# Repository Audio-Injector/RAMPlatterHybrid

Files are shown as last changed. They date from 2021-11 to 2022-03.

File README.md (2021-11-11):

# RAM Platter Hybrid

Hybrid software / hardware DJ kit

RAM Platter Hybrid

The RAM Platter Hybrid is a hardware and software to allow digital DJing of your music.

The system implements speed change resampling in hardware. The software provides the interface and controls the audio (direction) and other signal processing.

By performing resampling in hardware, the majority of the core signal processing does not burden the CPU. This allows the system to run on low power devices. It should also allow the system latency (time lag between moving the record and hearing it move) to be reduced.

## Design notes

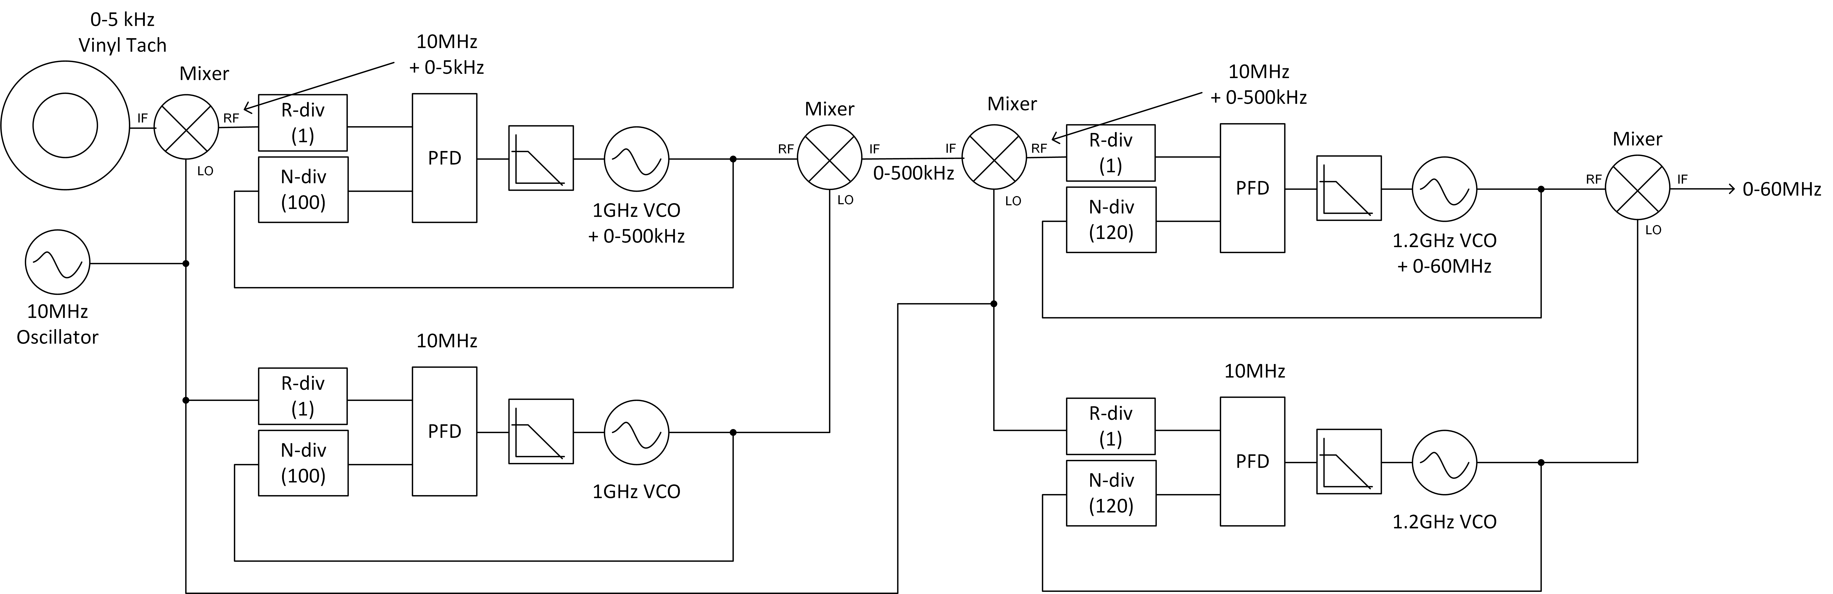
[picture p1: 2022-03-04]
electronics/wikiFigs/cascaded.mixer.png

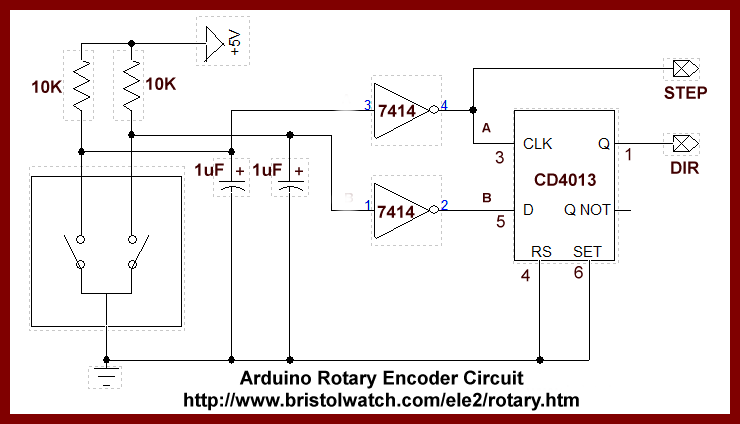
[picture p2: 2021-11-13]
electronics/datasheets/rot_enc.png

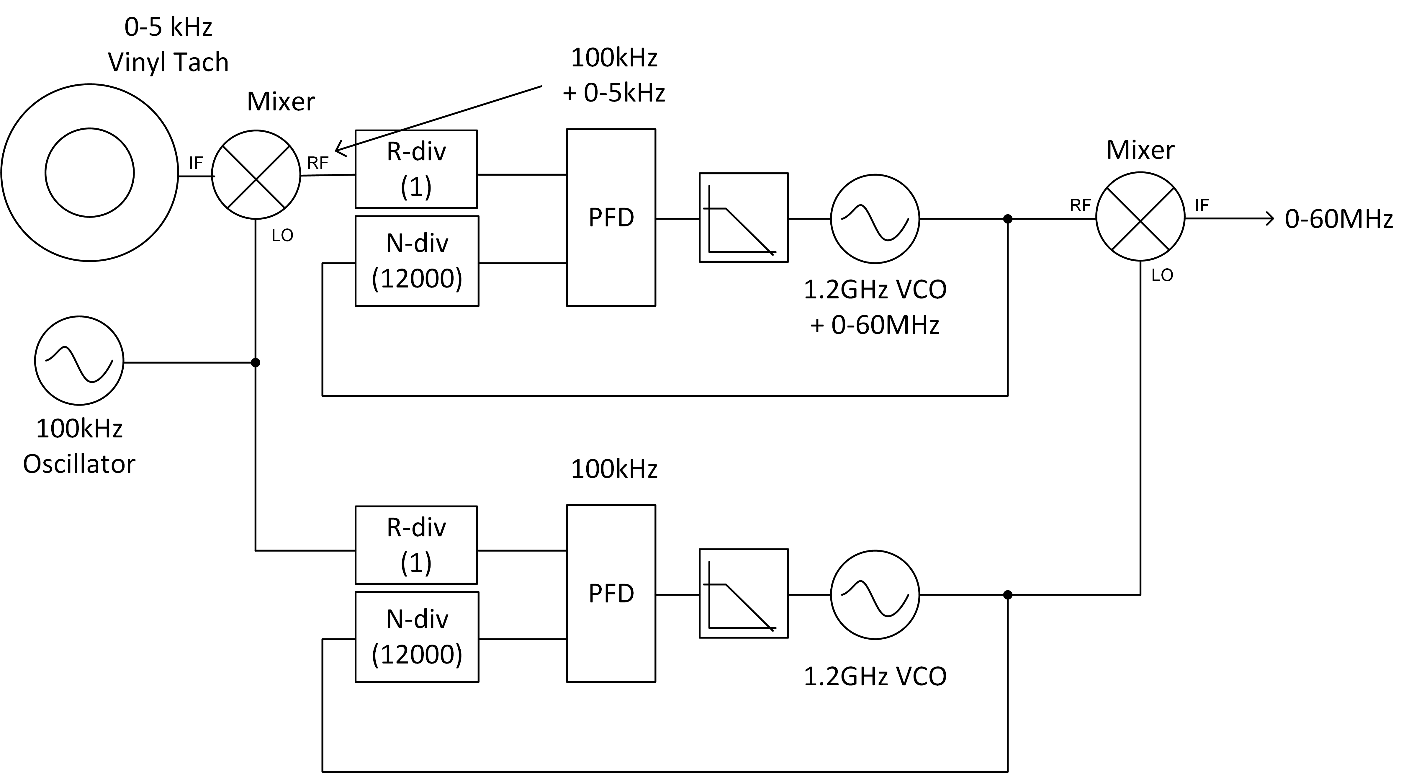
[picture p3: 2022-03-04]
electronics/wikiFigs/RFMixer.png

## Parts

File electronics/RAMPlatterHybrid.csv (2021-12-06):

Id | Designator | Package | Quantity | Designation | Supplier and ref
1 | U6 | SOIC-24W_7.5x15.4mm_P1.27mm | 1 | CD74HC4059
2 | R5,R6 | R_0603_1608Metric | 2 | 100R
3 | R7,R8,R9,R10 | R_0603_1608Metric | 4 | 75R
4 | U4,U3 | AV2-8.4-10 | 2 | AV2-8.4-10
5 | U7 | SOT-223-3_TabPin2 | 1 | AP1117-33
6 | U8 | QFN-32-1EP_5x5mm_P0.5mm_EP3.3x3.3mm | 1 | WM8750
7 | J1 | PinHeader_2x20_P2.54mm_Vertical | 1 | Raspberry_Pi_2_3
8 | C1,C2,C20 | C_0603_1608Metric | 3 | 2.5n
9 | C3,C4,C5,C6,C7,C9,C15,C17,C18,C19,C21,C22 | C_0603_1608Metric | 12 | 100n
10 | R1,R2 | R_0603_1608Metric | 2 | 20R
11 | R3,R4,R11 | R_0603_1608Metric | 3 | 10k
12 | U1 | SOP-8_3.9x4.9mm_P1.27mm | 1 | LM358
13 | U2 | TSSOP-14_4.4x5mm_P0.65mm | 1 | 74LVC74APW
14 | C23 | C_0603_1608Metric | 1 | 20n
15 | R12 | R_0603_1608Metric | 1 | 150k
16 | U5 | SOP-16_3.9x9.9mm_P1.27mm | 1 | HC4046A
17 | JP1,JP2,JP3 | SolderJumper-2_P1.3mm_Bridged_Pad1.0x1.5mm | 3 | SolderJumper_2_Bridged
18 | C8,C10,C16 | CP_Elec_4x5.3 | 3 | 10u
19 | C11,C12,C13,C14 | CP_Elec_4x5.3 | 4 | 1u NP

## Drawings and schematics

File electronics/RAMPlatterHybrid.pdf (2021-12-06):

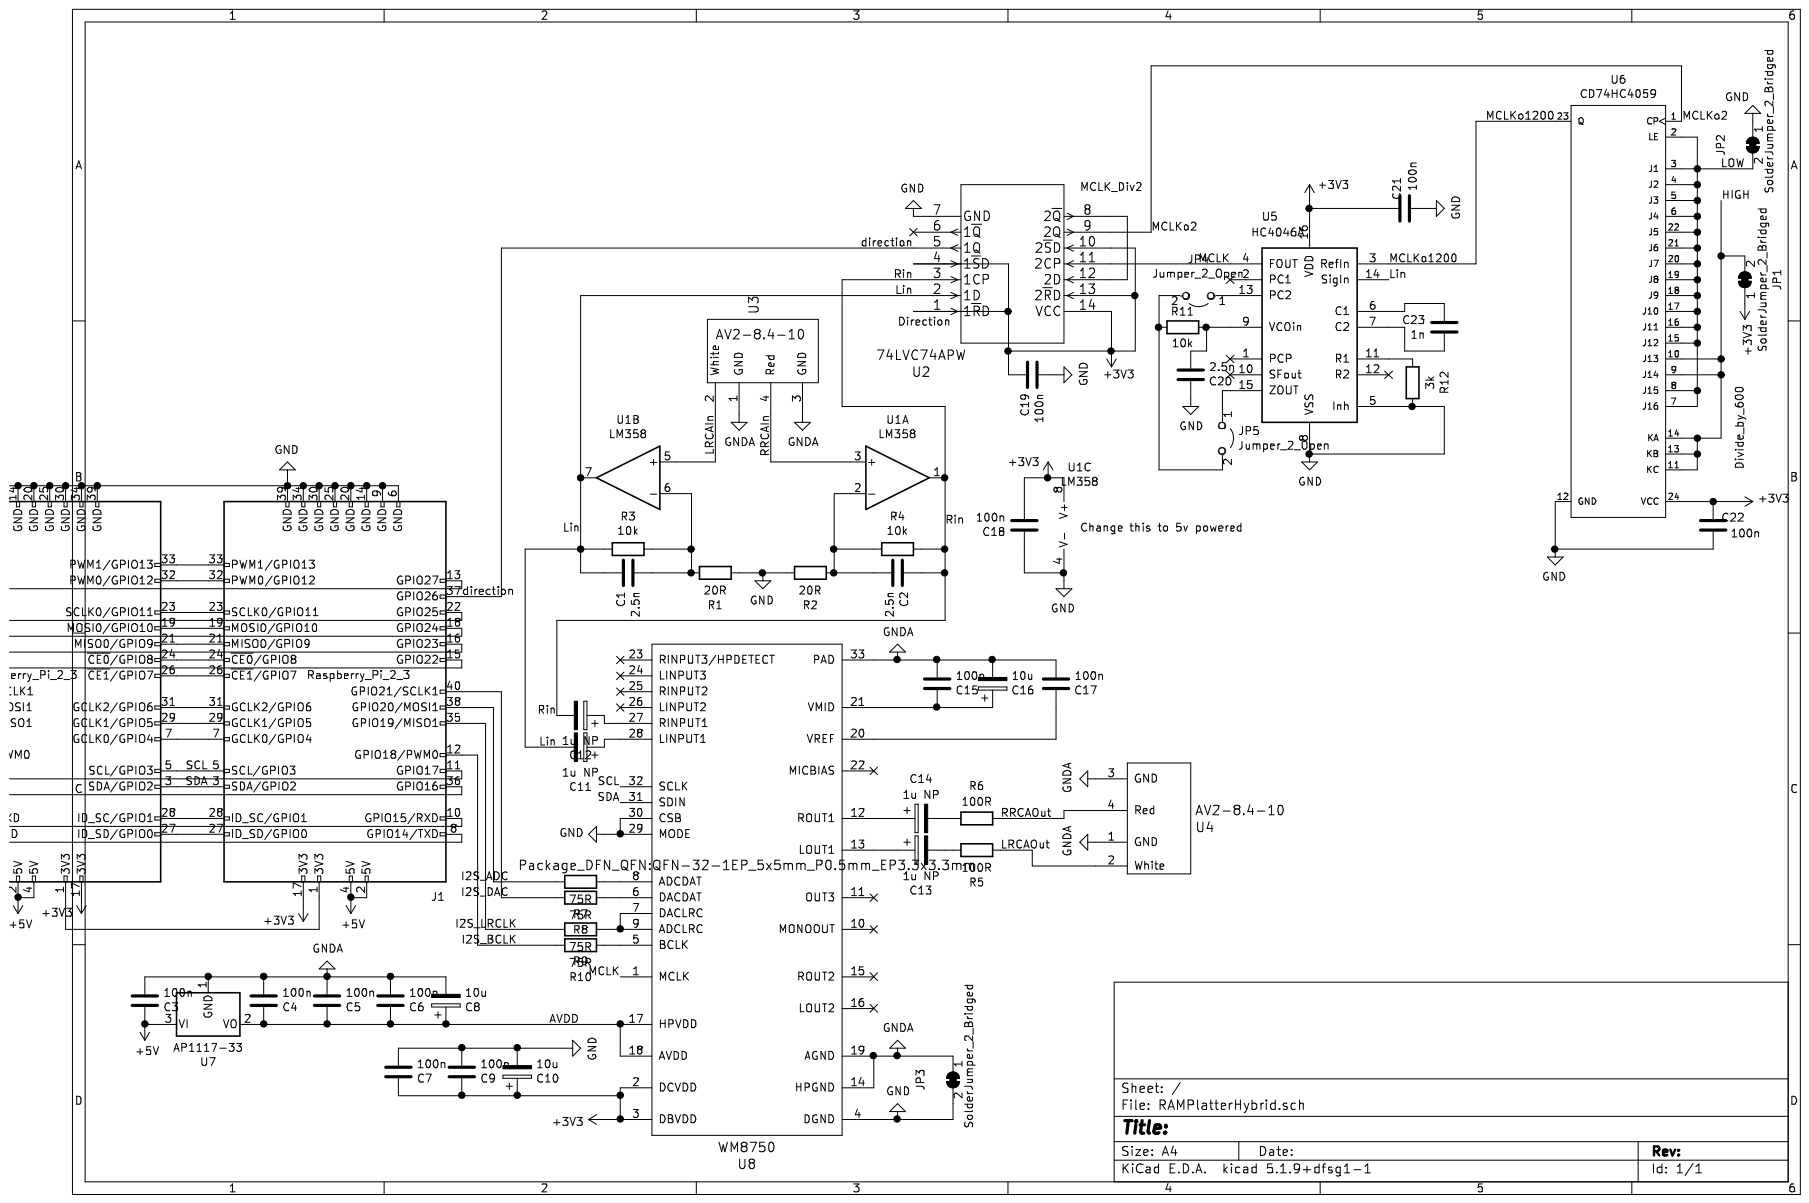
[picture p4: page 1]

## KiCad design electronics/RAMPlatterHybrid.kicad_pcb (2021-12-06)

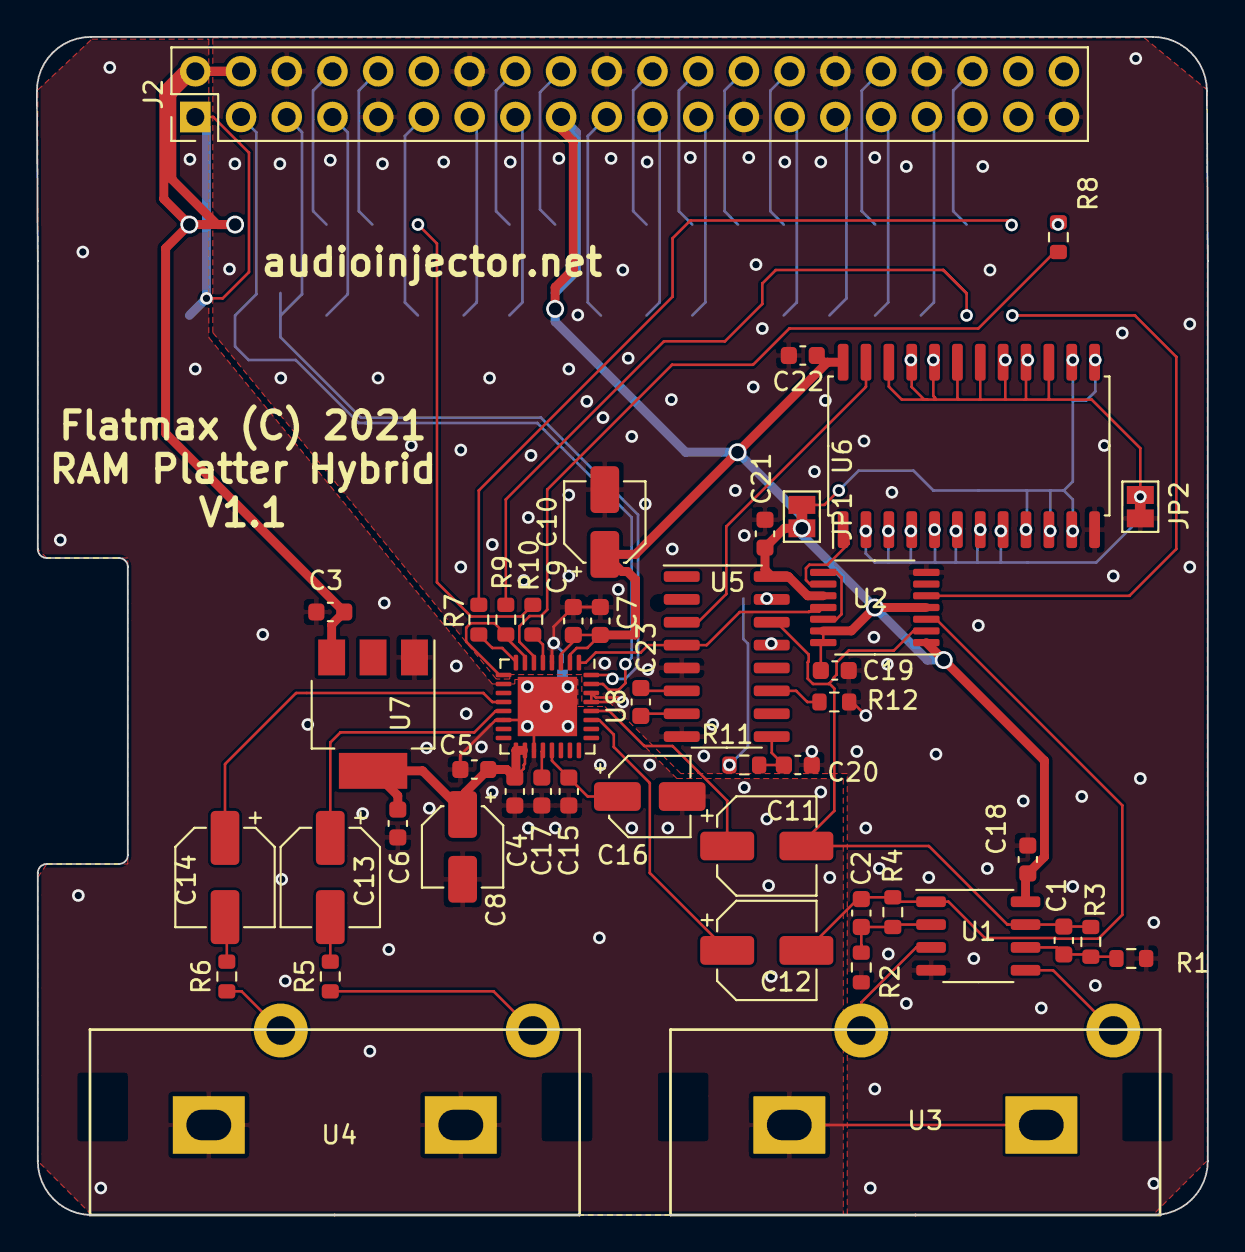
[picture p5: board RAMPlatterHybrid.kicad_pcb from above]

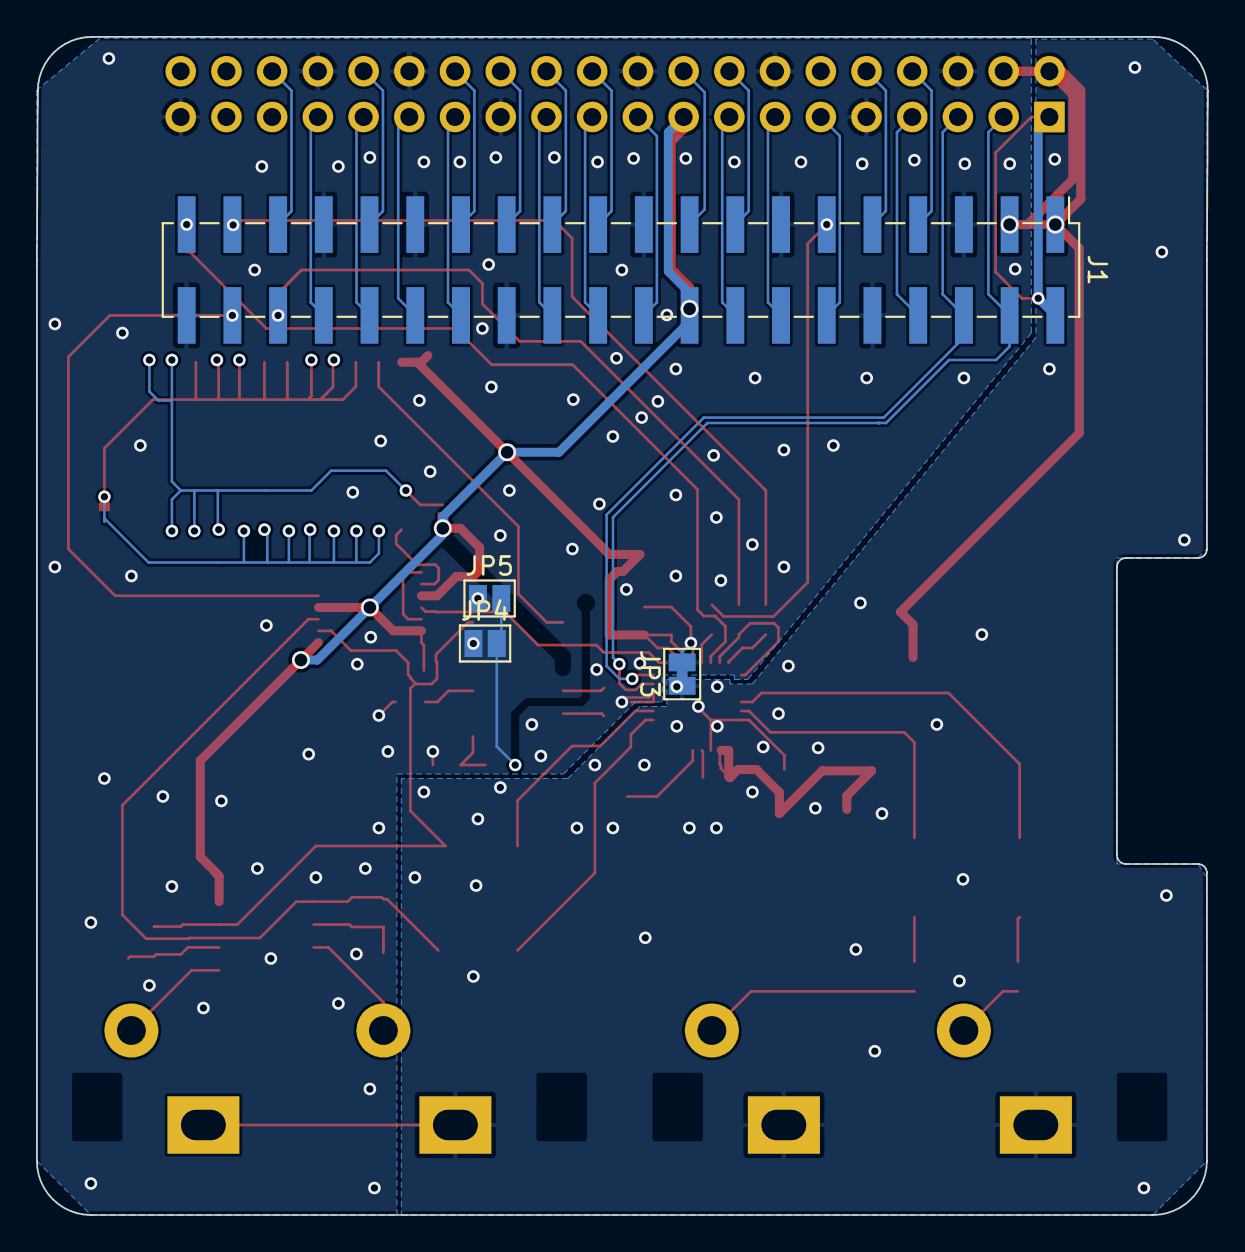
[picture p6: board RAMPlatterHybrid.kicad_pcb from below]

Board: 2 copper layers, 65.1 x 65.5 mm, 50 parts (4 on the bottom side), 67 nets.

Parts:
C1, C2, C20: 2.5n; C_0603_1608Metric
C3, C4, C5, C6, C7, C9, C15, C17, C18, C19, C21, C22: 100n; C_0603_1608Metric
C8, C10, C16: 10u; CP_Elec_4x5.3
C11, C12, C13, C14: 1u NP; CP_Elec_5x5.3
C23: 1n; C_0603_1608Metric
J1: Raspberry_Pi_2_3; 02x20.SMD.pinLocsRev
J2: Raspberry_Pi_2_3; PinHeader_2x20_P2.54mm_Vertical
JP1, JP2, JP3: SolderJumper_2_Bridged; SolderJumper-2_P1.3mm_Bridged_Pad1.0x1.5mm
JP4, JP5: Jumper_2_Open; SolderJumper-2_P1.3mm_Open_Pad1.0x1.5mm
R1, R2: 20R; R_0603_1608Metric
R3, R4, R11: 10k; R_0603_1608Metric
R5, R6: 100R; R_0603_1608Metric
R7, R8, R9, R10: 75R; R_0603_1608Metric
R12: 3k; R_0603_1608Metric
U1: LM358; SOP-8_3.9x4.9mm_P1.27mm
U2: 74LVC74APW; TSSOP-14_4.4x5mm_P0.65mm
U3, U4: AV2-8.4-10
U5: HC4046A; SOP-16_3.9x9.9mm_P1.27mm
U6: CD74HC4059; SOIC-24W_7.5x15.4mm_P1.27mm
U7: AP1117-33; SOT-223-3_TabPin2
U8: WM8750; QFN-32-1EP_5x5mm_P0.5mm_EP3.3x3.3mm

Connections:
+3V3: C7.1, C9.1, C10.1, C18.2, C19.1, C21.1, C22.1, J1.17, J2.17, JP1.1, U1.8, U2.1, U2.4, U2.10, U2.13, U2.14, U5.16, U6.24, U8.2, U8.3
+5V: C3.1, J1.2, J1.4, J2.2, J2.4, U7.3
/AVDD: C4.1, C5.1, C6.1, C8.1, U7.2, U8.17, U8.18
/HIGH: JP1.2, U6.9, U6.10, U6.11, U6.13, U6.14
/I2S_ADC: J1.38, R7.2
/I2S_BCLK: J1.12, R10.2
/I2S_DAC: J1.40, R8.2
/I2S_LRCLK: J1.35, R9.2
/LOW: JP2.2, U6.2, U6.3, U6.4, U6.5, U6.6, U6.7, U6.8, U6.15, U6.16, U6.17, U6.18, U6.19, U6.20, U6.21, U6.22
/LRCAIn: U1.5, U3.2
/LRCAOut: R5.1, U4.2
/Lin: C1.1, C11.2, R3.1, U1.7, U2.2, U5.14
/MCLK: U2.11, U5.4, U8.1
/MCLKo2: U2.9, U6.1
/MCLKo1200: U5.3, U6.23
/RRCAIn: U1.3, U3.4
/RRCAOut: R6.1, U4.4
/Rin: C2.1, C12.2, R4.1, U1.1, U2.3
/SCL: J1.5, J2.5, U8.32
/SDA: J1.3, J2.3, U8.31
/direction: J1.37, U2.5
GND: C7.2, C9.2, C10.2, C18.1, C19.2, C20.1, C21.2, C22.2, J1.6, J1.9, J1.14, J1.20, J1.25, J1.30, J1.34, J1.39, J2.6, J2.9, J2.14, J2.20, J2.25, J2.30, J2.34, J2.39, JP2.1, JP3.2, R1.1, R2.1, R12.2, U1.4, U2.7, U5.5, U5.8, U6.12, U8.4, U8.29, U8.30
GNDA: C3.2, C4.2, C5.2, C6.2, C8.2, C15.2, C16.2, C17.2, JP3.1, U3.1, U3.3, U4.1, U4.3, U7.1, U8.14, U8.19, U8.33
unnamed: C1.2, R1.2, R3.2, U1.6
unnamed: C2.2, R2.2, R4.2, U1.2
unnamed: C11.1, U8.28
unnamed: C12.1, U8.27
unnamed: C13.1, U8.13
unnamed: C13.2, R5.2
unnamed: C14.1, U8.12
unnamed: C14.2, R6.2
unnamed: C15.1, C16.1, U8.21
unnamed: C17.1, U8.20
unnamed: C20.2, R11.2, U5.9
unnamed: C23.1, U5.6
unnamed: C23.2, U5.7
unnamed: J1.1, J2.1
unnamed: J1.7, J2.7
unnamed: J1.8, J2.8
unnamed: J1.10, J2.10
unnamed: J1.11, J2.11
unnamed: J1.13, J2.13
unnamed: J1.15, J2.15
unnamed: J1.16, J2.16
unnamed: J1.18, J2.18
unnamed: J1.19, J2.19
unnamed: J1.21, J2.21
unnamed: J1.22, J2.22
unnamed: J1.23, J2.23
unnamed: J1.24, J2.24
unnamed: J1.26, J2.26
unnamed: J1.27, J2.27
unnamed: J1.28, J2.28
unnamed: J1.29, J2.29
unnamed: J1.31, J2.31
unnamed: J1.32, J2.32
unnamed: J1.33, J2.33
unnamed: J1.36, J2.36
unnamed: JP4.1, U5.13
unnamed: JP4.2, JP5.2, R11.1
unnamed: JP5.1, U5.15
unnamed: R7.1, U8.8
unnamed: R8.1, U8.6
unnamed: R9.1, U8.7, U8.9
unnamed: R10.1, U8.5
unnamed: R12.1, U5.11
unnamed: U2.8, U2.12

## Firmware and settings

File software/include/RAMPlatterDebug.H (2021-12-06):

// Copyright (c) 2017-2021 RAM Platter Hybrid Authors. All rights reserved.
//
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
//    * Redistributions of source code must retain the above copyright
// notice, this list of conditions and the following disclaimer.
//    * Redistributions in binary form must reproduce the above
// copyright notice, this list of conditions and the following disclaimer
// in the documentation and/or other materials provided with the
// distribution.
//    * Neither the name of mad chops coder AU nor the names of its
// contributors may be used to endorse or promote products derived from
// this software without specific prior written permission.
//
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
#ifndef RAMPLATTERDEBUG_H_
#define RAMPLATTERDEBUG_H_

#include <Debug.H>
#include <string>

#define RAMPLATTER_BYTEDEPTH_ERROR MIN_ERROR_OFFSET-1
#define RAMPLATTER_AUDIOEMPTY_ERROR MIN_ERROR_OFFSET-2
#define RAMPLATTER_FS_ERROR MIN_ERROR_OFFSET-3
#define RAMPLATTER_BLOCKSIZE_ERROR MIN_ERROR_OFFSET-4
#define RAMPLATTER_ALSA_STATE_ERROR MIN_ERROR_OFFSET-5

/** Class to handle errors
*/
class RAMPlatterDebug : virtual public Debug {
public:
  /** Constructor
  */
  RAMPlatterDebug(){
    #ifndef NDEBUG
    errors[RAMPLATTER_BYTEDEPTH_ERROR]=std::string("The word byte depth is incorrect.");
    errors[RAMPLATTER_AUDIOEMPTY_ERROR]=std::string("The audio hasn't been loaded yet, load audio first.");
    errors[RAMPLATTER_FS_ERROR]=std::string("The audio hardware's sample rate is incorrect.");
    errors[RAMPLATTER_BLOCKSIZE_ERROR]=std::string("The ALSA block size is incorrect.");
    errors[RAMPLATTER_ALSA_STATE_ERROR]=std::string("The ALSA system is in the wrong state.");
    #endif
  }

  /** Destructor
  */
  virtual ~RAMPlatterDebug(){}
};

#endif // RAMPLATTERDEBUG_H_

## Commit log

2021-11-13 began layout
    [RAMPlatterHybrid.kicad_pcb, RAMPlatterHybrid.sch]
2021-11-16 Added gerbers
    [RAMPlatterHybrid-B_Cu.gbl, RAMPlatterHybrid-B_Mask.gbs, RAMPlatterHybrid-B_Paste.gbp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]
2021-11-26 PlatterALSA now opening and setting up the audio device.
2021-11-26 Add 96 kHz sample rate capability.
2021-12-06 v1.1 Many hardware bug fixes, 4059 now dividing correctly. 4046 voc on better target, still debugging 4046 PLL.
    [RAMPlatterHybrid.csv, RAMPlatterHybrid.kicad_pcb, RAMPlatterHybrid.sch]
2021-12-06 addd RCA symbol and footprint
2021-12-06 added a pdf
    [RAMPlatterHybrid.sch]
2022-03-04 added a wiki link to the new required hardware to the sch file.
    [RAMPlatterHybrid.sch]

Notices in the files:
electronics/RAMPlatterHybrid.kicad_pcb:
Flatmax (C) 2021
